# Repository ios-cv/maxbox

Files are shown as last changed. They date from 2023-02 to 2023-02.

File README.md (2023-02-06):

MaxBox open-source hardware
====================

This repository is for the 3D design files, KiCad PCB design/Gerber files, and ESP-IDF firmware files to produce a MaxBox control box. This takes the form of a 100mm diameter circular PCB with a Mifare antenna, buck converter capable of up to 36V DC input, RGB LEDs, high speed CAN bus transceiver, an ESP32-WROVER castellated module incorporating a Bluetooth and WiFi antenna, and GPIO to connect buttons and relays.

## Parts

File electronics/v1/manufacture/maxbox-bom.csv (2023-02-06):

Comment | Designator | Footprint | LCSC
10u 50V | C1 | Capacitor_SMD:C_0805_2012Metric | C440198
10u | C11,C25,C29 | Capacitor_SMD:C_0402_1005Metric | C15525
12p | C15,C16 | Capacitor_SMD:C_0805_2012Metric | C1792
122pF | C17,C18 | Capacitor_SMD:C_0603_1608Metric | C18438
41.8pF | C19,C22 | Capacitor_SMD:C_0805_2012Metric | C502147
4.7u 50V | C2 | Capacitor_SMD:C_1206_3216Metric | C29823
1n | C21 | Capacitor_SMD:C_0402_1005Metric | C1523
82.8pF | C23,C24 | Capacitor_SMD:C_0805_2012Metric | C105942
10p | C28 | Capacitor_SMD:C_0402_1005Metric | C32949
100n 50V | C3,C4 | Capacitor_SMD:C_0402_1005Metric | C307331
560p | C31,C32 | Capacitor_SMD:C_0402_1005Metric | C1537
1u | C5,C7 | Capacitor_SMD:C_0402_1005Metric | C52923
100n | C6,C10,C12,C13,C14,C20,C26,C27,C30,C35 | Capacitor_SMD:C_0402_1005Metric | C307331
22u | C8,C9,C33,C34 | Capacitor_SMD:C_0805_2012Metric | C45783
STATUS | D1 | LED_SMD:LED_0603_1608Metric | C72043
NUP2105L | D3 | Package_TO_SOT_SMD:SOT-23 | C284104
RGBLED | D4,D5,D6,D7,D8,D9,D10,D11 | maxlibrary:LED_FM-Z2727RGBA-SH | C727905
TC2030-IDC-NL_ESP | J1 | Connector:Tag-Connect_TC2030-IDC-NL_2x03_P1.27mm_Vertical
PICOBLADE | J2 | Connector_Molex:Molex_PicoBlade_53261-0671_1x06-1MP_P1.25mm_Horizontal | C99277
6.8uH | L1 | maxlibrary:L_Cenker_CKST0603 | C3002639
470nH | L2,L3 | Inductor_SMD:L_0805_2012Metric | C655211
AO3400A | Q1,Q2,Q3 | Package_TO_SOT_SMD:SOT-23 | C20917
100k 1% | R1 | Resistor_SMD:R_0402_1005Metric | C25741
470K | R11 | Resistor_SMD:R_0402_1005Metric | C25790
100K | R12 | Resistor_SMD:R_0402_1005Metric | C25741
470R | R13,R14 | Resistor_SMD:R_0402_1005Metric | C25117
100R | R15,R16 | Resistor_SMD:R_0402_1005Metric | C25076
43.2k 1% | R2 | Resistor_SMD:R_0603_1608Metric | C23172
75R | R21,R24,R27,R30,R33,R36,R39,R42 | Resistor_SMD:R_0402_1005Metric | C25133
33R | R22,R23,R25,R26,R28,R29,R31,R32,R34,R35,R37,R38,R40,R41,R43,R44 | Resistor_SMD:R_0402_1005Metric | C25105
1k | R3 | Resistor_SMD:R_0402_1005Metric | C11702
2.7k | R4,R17 | Resistor_SMD:R_0603_1608Metric | C13167
3.24R | R5,R6 | Resistor_SMD:R_0402_1005Metric | C270612
12K | R7,R9 | Resistor_SMD:R_0402_1005Metric | C25752
220R | R8,R10,R18,R19,R20 | Resistor_SMD:R_0402_1005Metric | C25091
RESET | SW1 | maxlibrary:XKB_TS-1187A-B-A-B | C318884
LMR33630ARNXT | U1 | maxlibrary:RNX0012B_VQFN-HR | C2861505
MFRC522 | U2 | Package_DFN_QFN:VQFN-32-1EP_5x5mm_P0.5mm_EP3.5x3.5mm_ThermalVias | C11322
ESP32-WROOM-32E-N4 | U3 | RF_Module:ESP32-WROOM-32 | C701341
SN65HVD230 | U4 | Package_SO:SOIC-8_3.9x4.9mm_P1.27mm | C12084
27.12MHz | Y1 | Crystal:Crystal_SMD_3225-4Pin_3.2x2.5mm | C113669

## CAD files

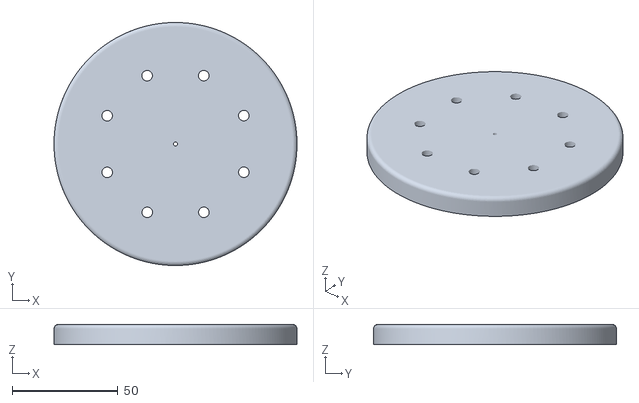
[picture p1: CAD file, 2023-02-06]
case/case-top.stl
115.0 x 115.0 x 9.50

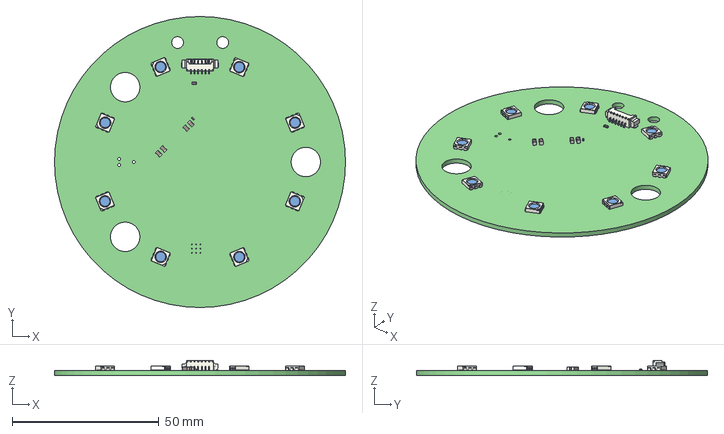
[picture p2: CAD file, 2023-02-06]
case/pcb-v1.step
99.0 x 99.0 x 5.05 mm
CanHireEV PCB

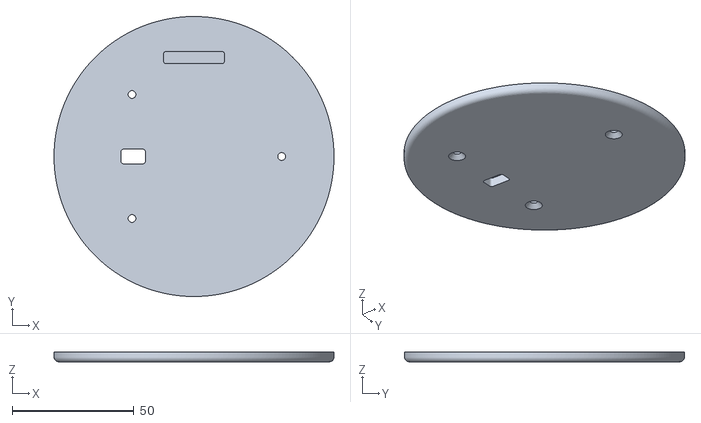
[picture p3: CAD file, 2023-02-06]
case/case-bottom.stl
115.0 x 115.0 x 4.00

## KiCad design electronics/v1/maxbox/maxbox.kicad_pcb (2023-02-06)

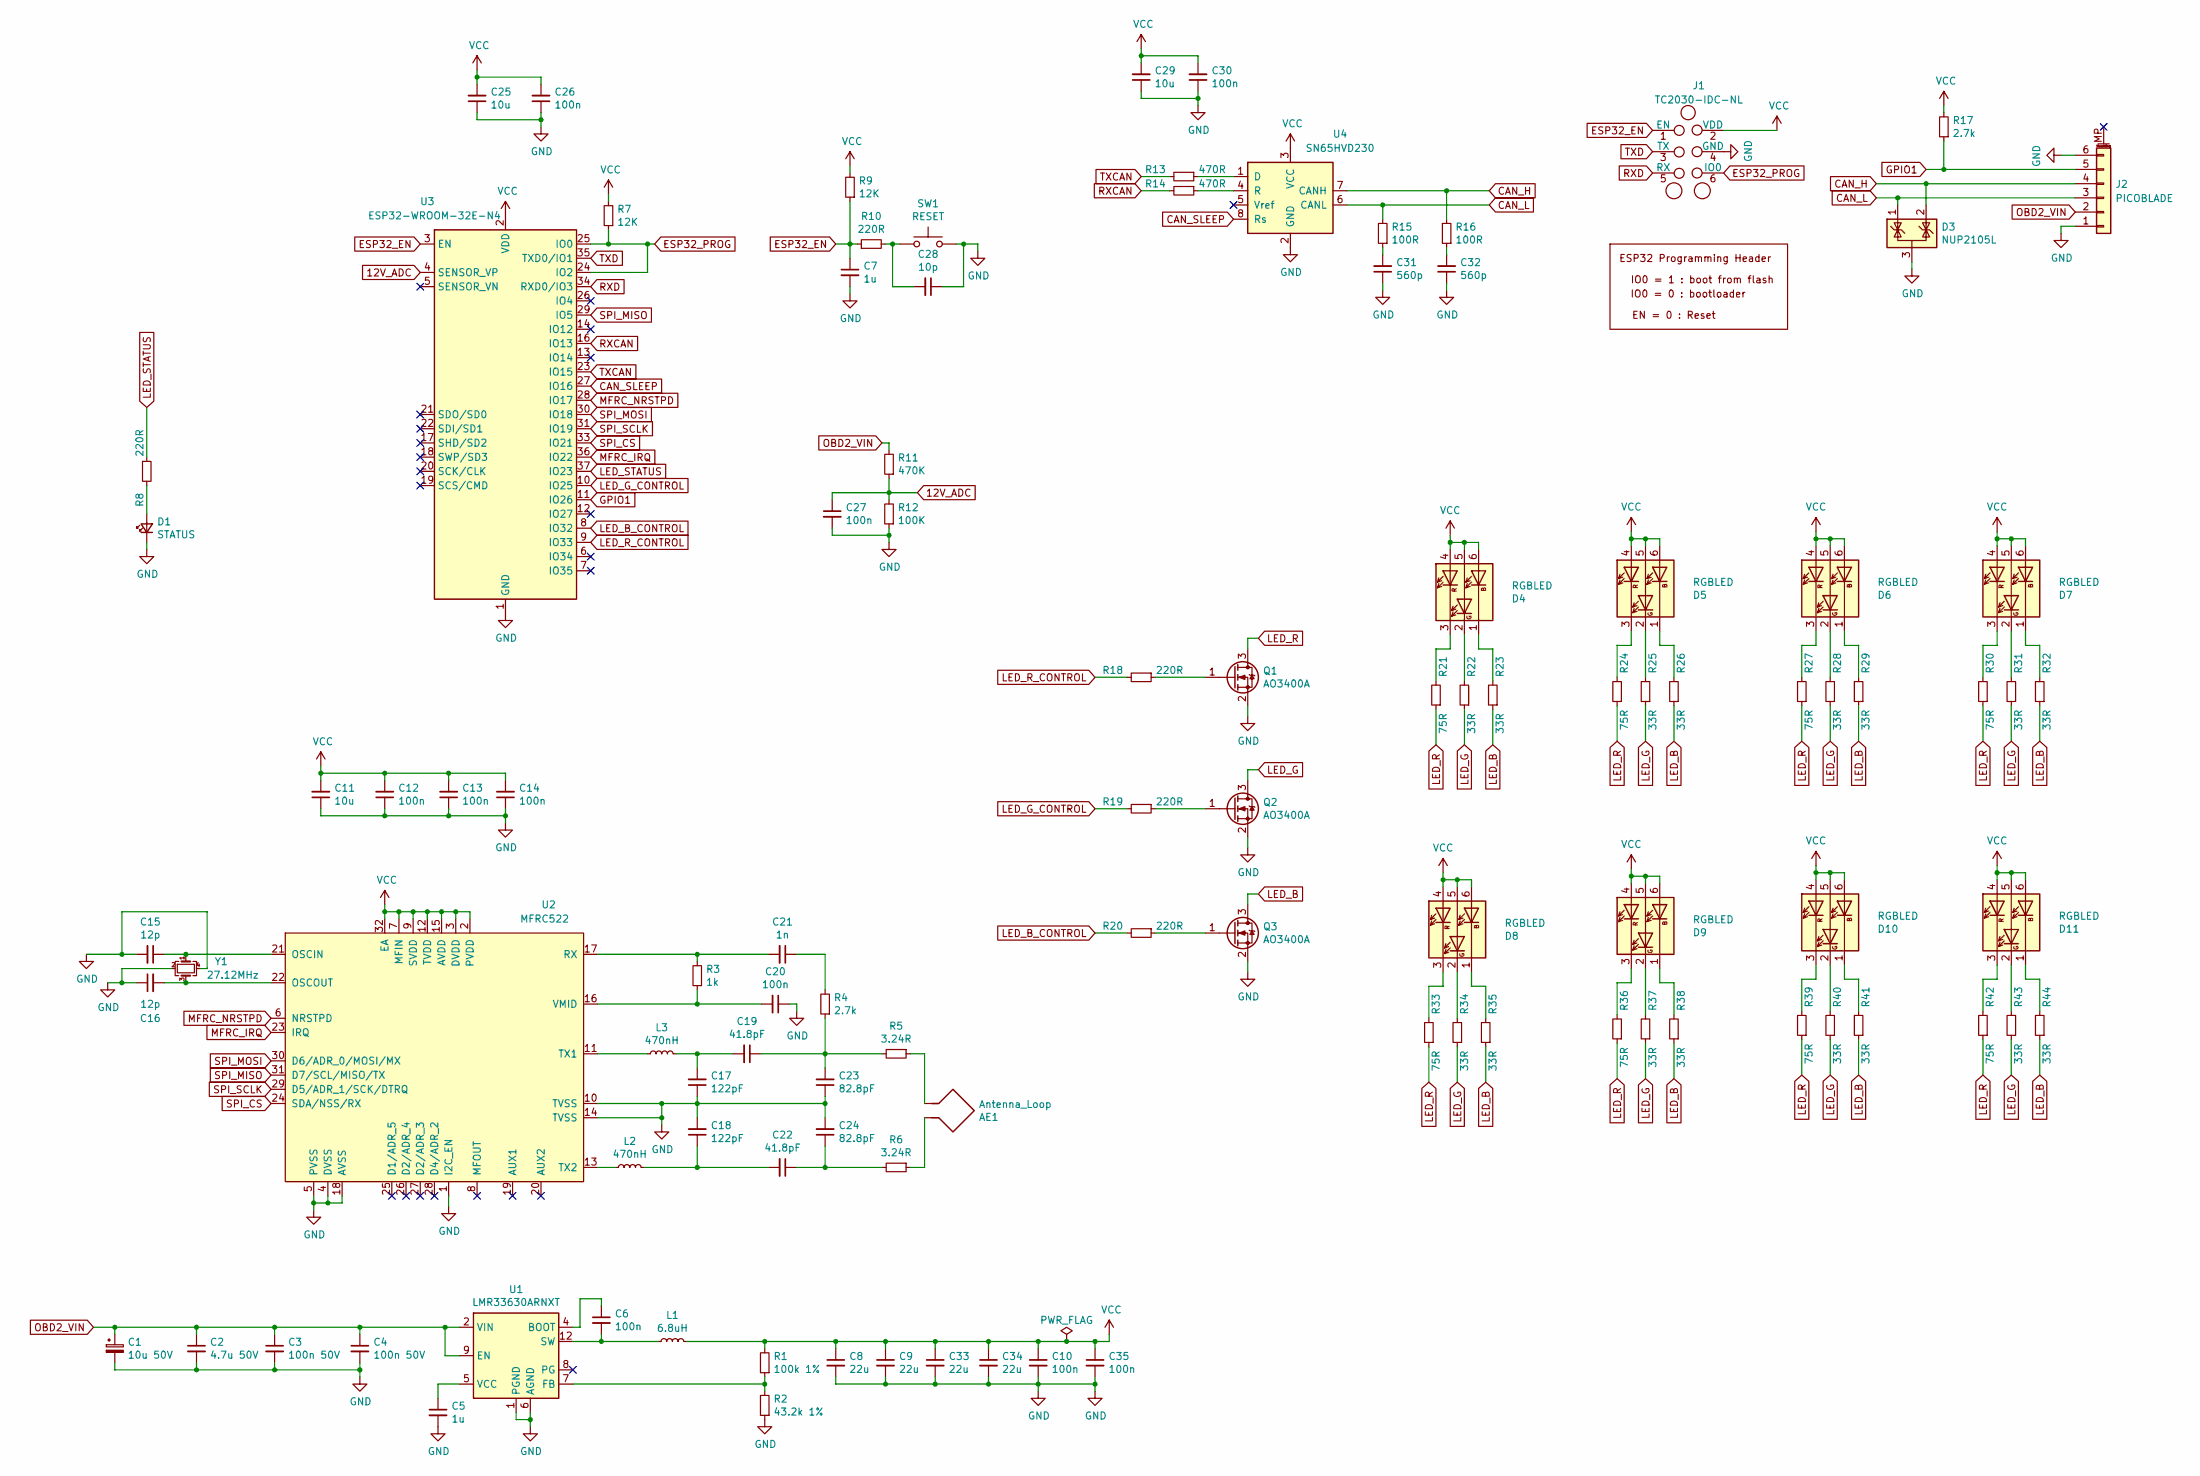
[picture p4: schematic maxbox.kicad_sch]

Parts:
AE1: Antenna_Loop; 95mm-3turn-antenna
C1: 10u 50V; C_0805_2012Metric; LCSC C440198
C2: 4.7u 50V; C_1206_3216Metric; LCSC C29823
C3, C4: 100n 50V; C_0402_1005Metric; LCSC C307331
C5, C7: 1u; C_0402_1005Metric; LCSC C52923
C6, C10, C12, C13, C14, C20, C26, C27, C30, C35: 100n; C_0402_1005Metric; LCSC C307331
C8, C9, C33, C34: 22u; C_0805_2012Metric; LCSC C45783
C11, C25, C29: 10u; C_0402_1005Metric; LCSC C15525
C15, C16: 12p; C_0805_2012Metric; LCSC C1792
C17, C18: 122pF; C_0603_1608Metric; LCSC C18438
C19, C22: 41.8pF; C_0805_2012Metric; LCSC C502147
C21: 1n; C_0402_1005Metric; LCSC C1523
C23, C24: 82.8pF; C_0805_2012Metric; LCSC C105942
C28: 10p; C_0402_1005Metric; LCSC C32949
C31, C32: 560p; C_0402_1005Metric; LCSC C1537
D1: STATUS; LED_0603_1608Metric; LCSC C72043
D3: NUP2105L; SOT-23; LCSC C284104
D4, D5, D6, D7, D8, D9, D10, D11: RGBLED; LED_FM-Z2727RGBA-SH; LCSC C727905
J1: TC2030-IDC-NL_ESP; Tag-Connect_TC2030-IDC-NL_2x03_P1.27mm_Vertical
J2: PICOBLADE; Molex_PicoBlade_53261-0671_1x06-1MP_P1.25mm_Horizontal; LCSC C99277
L1: 6.8uH; L_Cenker_CKST0603; LCSC C3002639
L2, L3: 470nH; L_0805_2012Metric; LCSC C655211
Q1, Q2, Q3: AO3400A; SOT-23; LCSC C20917
R1: 100k 1%; R_0402_1005Metric; LCSC C25741
R2: 43.2k 1%; R_0603_1608Metric; LCSC C23172
R3: 1k; R_0402_1005Metric; LCSC C11702
R4, R17: 2.7k; R_0603_1608Metric; LCSC C13167
R5, R6: 3.24R; R_0402_1005Metric; LCSC C270612
R7, R9: 12K; R_0402_1005Metric; LCSC C25752
R8, R10, R18, R19, R20: 220R; R_0402_1005Metric; LCSC C25091
R11: 470K; R_0402_1005Metric; LCSC C25790
R12: 100K; R_0402_1005Metric; LCSC C25741
R13, R14: 470R; R_0402_1005Metric; LCSC C25117
R15, R16: 100R; R_0402_1005Metric; LCSC C25076
R21, R24, R27, R30, R33, R36, R39, R42: 75R; R_0402_1005Metric; LCSC C25133
R22, R23, R25, R26, R28, R29, R31, R32, R34, R35, R37, R38, R40, R41, R43, R44: 33R; R_0402_1005Metric; LCSC C25105
SW1: RESET; XKB_TS-1187A-B-A-B; LCSC C318884
U1: LMR33630ARNXT; RNX0012B_VQFN-HR; LCSC C2861505
U2: MFRC522; VQFN-32-1EP_5x5mm_P0.5mm_EP3.5x3.5mm_ThermalVias; LCSC C11322
U3: ESP32-WROOM-32E-N4; ESP32-WROOM-32; LCSC C701341
U4: SN65HVD230; SOIC-8_3.9x4.9mm_P1.27mm; LCSC C12084
Y1: 27.12MHz; Crystal_SMD_3225-4Pin_3.2x2.5mm; LCSC C113669

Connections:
12V_ADC: C27.1, R11.1, R12.2, U3.4 (SENSOR_VP)
CAN_H: D3.2 (K), J2.4, R16.2, U4.7 (CANH)
CAN_L: D3.1 (K), J2.3, R15.2, U4.6 (CANL)
CAN_SLEEP: U3.27 (IO16), U4.8 (Rs)
ESP32_EN: C7.1, J1.1 (EN), R9.1, R10.1, U3.3 (EN)
ESP32_PROG: J1.6 (IO0), R7.1, U3.24 (IO2), U3.25 (IO0)
GND: C1.2, C2.2, C3.2, C4.2, C5.2, C7.2, C8.2, C9.2, C10.2, C11.1, C12.1, C13.1, C14.1, C15.2, C16.1, C17.1, C18.2, C20.1, C23.1, C24.2, C25.1, C26.1, C27.2, C28.1, C29.1, C30.1, C31.1, C32.1, C33.2, C34.2, C35.2, D1.1 (K), D3.3 (A), J1.4 (GND), J2.1, J2.6, Q1.2 (S), Q2.2 (S), Q3.2 (S), R2.1, R12.1, SW1.2, U1.1 (PGND), U1.6 (AGND), U1.11 (PGND), U2.1 (I2C_EN), U2.4 (DVSS), U2.5 (PVSS), U2.10 (TVSS), U2.14 (TVSS), U2.18 (AVSS), U3.1 (GND), U3.15 (GND), U3.38 (GND), U3.39 (GND), U4.2 (GND), Y1.2, Y1.4
GPIO1: J2.5, R17.1, U3.11 (IO26)
LED_B: Q3.3 (D), R23.1, R26.1, R29.1, R32.1, R35.1, R38.1, R41.1, R44.1
LED_B_CONTROL: R20.2, U3.8 (IO32)
LED_G: Q2.3 (D), R22.1, R25.1, R28.1, R31.1, R34.1, R37.1, R40.1, R43.1
LED_G_CONTROL: R19.2, U3.10 (IO25)
LED_R: Q1.3 (D), R21.1, R24.1, R27.1, R30.1, R33.1, R36.1, R39.1, R42.1
LED_R_CONTROL: R18.2, U3.9 (IO33)
LED_STATUS: R8.1, U3.37 (IO23)
MFRC_IRQ: U2.23 (IRQ), U3.36 (IO22)
MFRC_NRSTPD: U2.6 (NRSTPD), U3.28 (IO17)
unnamed: AE1.1, R6.1
unnamed: AE1.2, R5.1
unnamed: C5.1, U1.5 (VCC)
unnamed: C6.1, U1.4 (BOOT)
unnamed: C6.2, L1.1, U1.3 (NC), U1.12 (SW)
unnamed: C15.1, U2.21 (OSCIN), Y1.1
unnamed: C16.2, U2.22 (OSCOUT), Y1.3
unnamed: C17.2, C19.2, L3.2
unnamed: C18.1, C22.2, L2.2
unnamed: C19.1, C23.2, R4.1, R5.2
unnamed: C20.2, R3.1, U2.16 (VMID)
unnamed: C21.1, R4.2
unnamed: C21.2, R3.2, U2.17 (RX)
unnamed: C22.1, C24.1, R6.2
unnamed: C28.2, R10.2, SW1.1
unnamed: C31.2, R15.1
unnamed: C32.2, R16.1
unnamed: D1.2 (A), R8.2
unnamed: D4.1 (KB), R23.2
unnamed: D4.2 (KG), R22.2
unnamed: D4.3 (KR), R21.2
unnamed: D5.1 (KB), R26.2
unnamed: D5.2 (KG), R25.2
unnamed: D5.3 (KR), R24.2
unnamed: D6.1 (KB), R29.2
unnamed: D6.2 (KG), R28.2
unnamed: D6.3 (KR), R27.2
unnamed: D7.1 (KB), R32.2
unnamed: D7.2 (KG), R31.2
unnamed: D7.3 (KR), R30.2
unnamed: D8.1 (KB), R35.2
unnamed: D8.2 (KG), R34.2
unnamed: D8.3 (KR), R33.2
unnamed: D9.1 (KB), R38.2
unnamed: D9.2 (KG), R37.2
unnamed: D9.3 (KR), R36.2
unnamed: D10.1 (KB), R41.2
unnamed: D10.2 (KG), R40.2
unnamed: D10.3 (KR), R39.2
unnamed: D11.1 (KB), R44.2
unnamed: D11.2 (KG), R43.2
unnamed: D11.3 (KR), R42.2
unnamed: L2.1, U2.13 (TX2)
unnamed: L3.1, U2.11 (TX1)
unnamed: Q1.1 (G), R18.1
unnamed: Q2.1 (G), R19.1
unnamed: Q3.1 (G), R20.1
unnamed: R1.1, R2.2, U1.7 (FB)
unnamed: R13.1, U4.1 (D)
unnamed: R14.1, U4.4 (R)
OBD2_VIN: C1.1, C2.1, C3.1, C4.1, J2.2, R11.2, U1.2 (VIN), U1.9 (EN), U1.10 (VIN)
RXCAN: R14.2, U3.16 (IO13)
RXD: J1.5 (RX), U3.34 (RXD0/IO3)
SPI_CS: U2.24 (SDA/NSS/RX), U3.33 (IO21)
SPI_MISO: U2.31 (D7/SCL/MISO/TX), U3.29 (IO5)
SPI_MOSI: U2.30 (D6/ADR_0/MOSI/MX), U3.30 (IO18)
SPI_SCLK: U2.29 (D5/ADR_1/SCK/DTRQ), U3.31 (IO19)
TXCAN: R13.2, U3.23 (IO15)
TXD: J1.3 (TX), U3.35 (TXD0/IO1)
VCC: C8.1, C9.1, C10.1, C11.2, C12.2, C13.2, C14.2, C25.2, C26.2, C29.2, C30.2, C33.1, C34.1, C35.1, D4.4 (AR), D4.5 (AG), D4.6 (AB), D5.4 (AR), D5.5 (AG), D5.6 (AB), D6.4 (AR), D6.5 (AG), D6.6 (AB), D7.4 (AR), D7.5 (AG), D7.6 (AB), D8.4 (AR), D8.5 (AG), D8.6 (AB), D9.4 (AR), D9.5 (AG), D9.6 (AB), D10.4 (AR), D10.5 (AG), D10.6 (AB), D11.4 (AR), D11.5 (AG), D11.6 (AB), J1.2 (VDD), L1.2, R1.2, R7.2, R9.2, R17.2, U2.2 (PVDD), U2.3 (DVDD), U2.7 (MFIN), U2.9 (SVDD), U2.12 (TVDD), U2.15 (AVDD), U2.32 (EA), U3.2 (VDD), U4.3 (VCC)

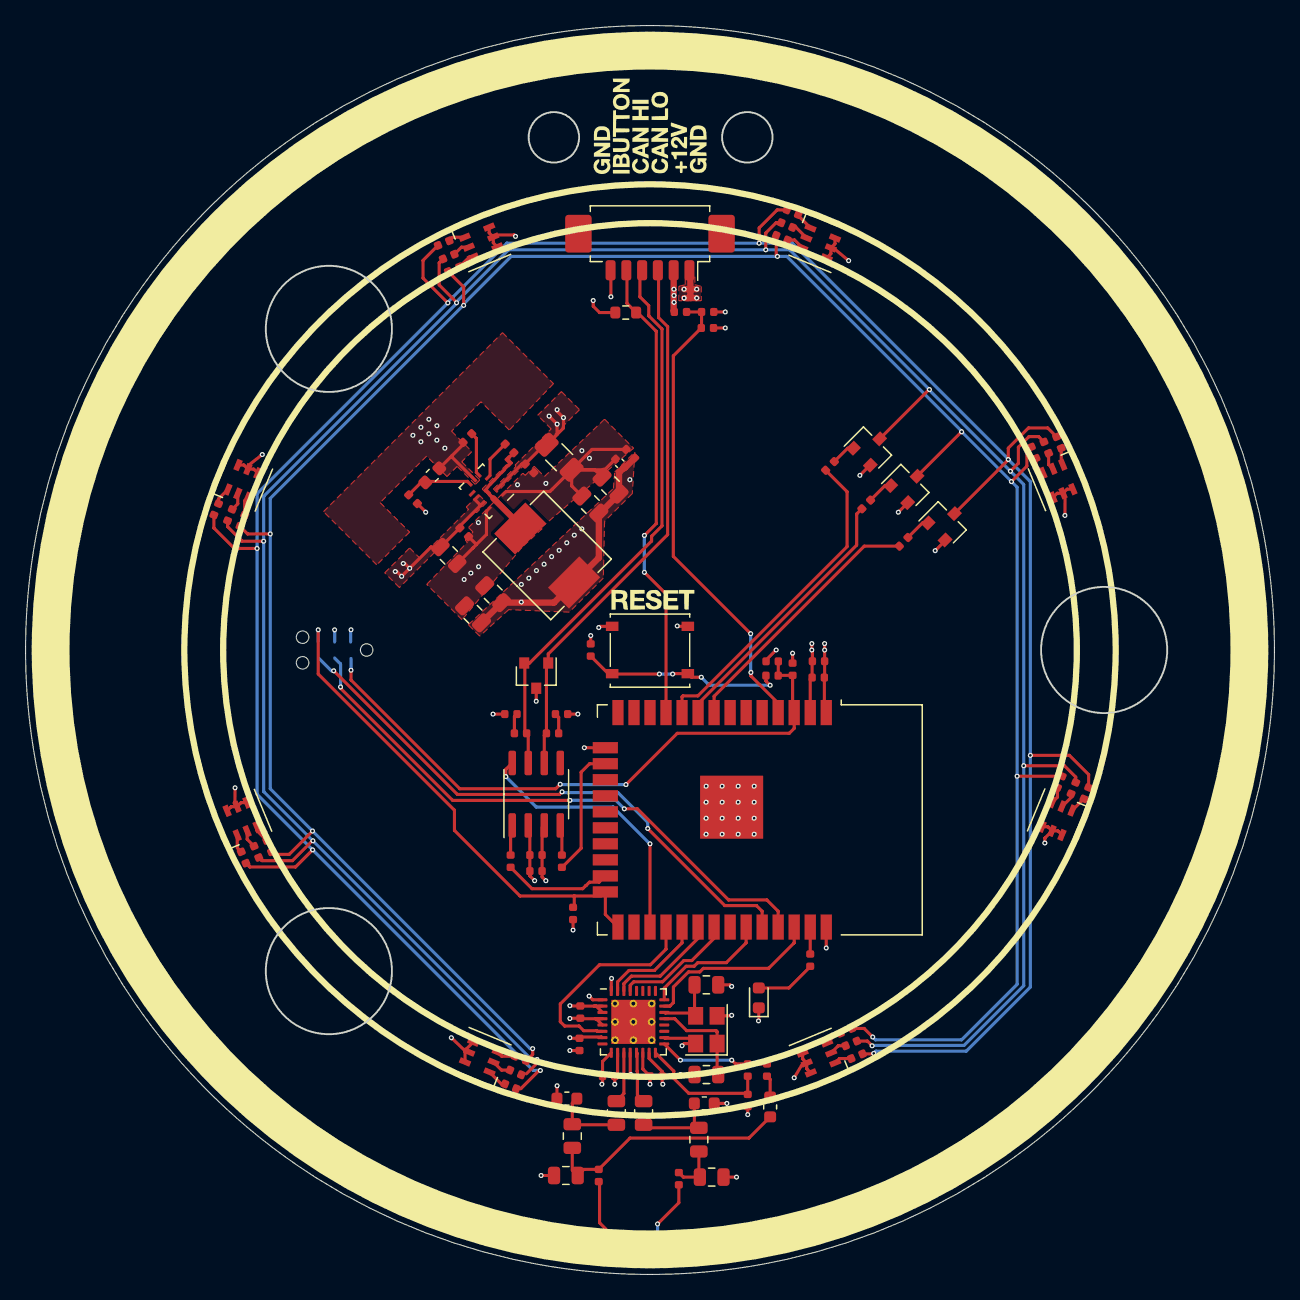
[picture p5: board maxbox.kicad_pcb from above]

Board: 4 copper layers, 99.0 x 99.0 mm, 104 parts (1 on the bottom side), 77 nets.

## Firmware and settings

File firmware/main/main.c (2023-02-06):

#include "stdio.h"
#include "string.h"
#include "driver/gpio.h"
#include "inttypes.h"

#include "freertos/FreeRTOS.h"
#include "freertos/event_groups.h"
#include "freertos/task.h"
#include "pthread.h"

#include "esp_log.h"
#include "driver/adc.h"
#include "esp_adc_cal.h"

#include "nvs_flash.h"
#include "cJSON.h"

#include "rc522.h"
#include "network.h"
#include "vehicle.h"
#include "led.h"
#include "owb.h"

#include <time.h>
#include <sys/time.h>
#include "freertos/task.h"
#include "driver/uart.h"
#include "esp_sleep.h"
#include "esp_log.h"
#include "esp_timer.h"
#include "esp_check.h"

// GPIO

#define RFID_MISO_PIN   5
#define RFID_MOSI_PIN   18
#define RFID_SCK_PIN    19
#define RFID_SDA_PIN    21
#define RFID_NRSTPD_PIN 17
#define RFID_IRQ_PIN    22

#define CAN_TX_PIN      15
#define CAN_RX_PIN      13
#define CAN_SLEEP_PIN   16

#define ONEWIRE_PIN     26

#define API_ENDPOINT_TOUCH          CONFIG_API_ROOT "touch"
#define API_ENDPOINT_TELEMETRY      CONFIG_API_ROOT "telemetry"

#define MAX_OPERATOR_CARDS          32

#define TAG_CHECK_INTERVAL_MS       500
#define TELEMETRY_SEND_INTERVAL_MS  120000

#define TELEMETRY_TIMEOUT_MS        8000
#define TOUCH_TIMEOUT_MS            20000

/* FreeRTOS event group to signal when it's safe to power off*/
EventGroupHandle_t s_status_group;

#define TELEMETRY_SENDING_BIT   BIT0 // currently sending telemetry
#define TELEMETRY_DONE_BIT      BIT1 // telemetry is sent
#define TAG_PROCESSING_BIT      BIT2 // currently processing a tag
#define TAG_DONE_BIT            BIT3 // tag processing is finished
#define FIRMWARE_UPDATING_BIT   BIT4 // firmware update in progress

static const char* TAG = "MaxBox";
static esp_adc_cal_characteristics_t adc1_chars;
rest_request_t touch_req;
rest_request_t telemetry_req;

char firmware_update_url[255] = {0};

struct maxbox {
    vehicle_t vehicle;
    int operator_car_lock;
    char operator_card_list[MAX_OPERATOR_CARDS][9];
};

int etag = -1;

OneWireBus * owb;
owb_rmt_driver_info rmt_driver_info;

typedef struct maxbox* maxbox_handle_t;

static maxbox_handle_t hndl = NULL;

static void io_init(void)
{
    // Power up the MFRC522
    gpio_set_direction(RFID_NRSTPD_PIN, GPIO_MODE_OUTPUT);
    gpio_set_level(RFID_NRSTPD_PIN, 1);

    // TODO: Sleep CAN transmitter until required (to save power) 
    // For the moment we just leave it awake all the time
    gpio_set_direction(CAN_SLEEP_PIN, GPIO_MODE_OUTPUT);
    gpio_set_level(CAN_SLEEP_PIN, 0);

    adc1_config_width(ADC_WIDTH_BIT_12);
    adc1_config_channel_atten(ADC1_CHANNEL_0,ADC_ATTEN_DB_11);
}

static void flash_init(void)
{
    //Initialize NVS
    esp_err_t ret = nvs_flash_init();
    if (ret == ESP_ERR_NVS_NO_FREE_PAGES || ret == ESP_ERR_NVS_NEW_VERSION_FOUND) {
      ESP_ERROR_CHECK(nvs_flash_erase());
      ret = nvs_flash_init();
    }
    ESP_ERROR_CHECK(ret);

    uint8_t base_mac[6] = {0};
    ESP_ERROR_CHECK(esp_read_mac(base_mac, ESP_MAC_WIFI_STA));

    ESP_LOGI(TAG, "Loaded NVS. Base MAC address %02x%02x%02x%02x%02x%02x", base_mac[0], base_mac[1], base_mac[2], base_mac[3], base_mac[4], base_mac[5]);

    nvs_handle_t my_handle;
    esp_err_t err = nvs_open("storage", NVS_READWRITE, &my_handle);
    if (err != ESP_OK) {
        ESP_LOGE(TAG, "Error (%s) opening NVS handle!", esp_err_to_name(err));
    } else {
        ESP_LOGI(TAG, "Reading operator card list from NVS ...");
        nvs_get_i32(my_handle, "etag", &etag);

        size_t required_size = sizeof(hndl->operator_card_list);
        nvs_get_blob(my_handle, "op_card_list", hndl->operator_card_list, &required_size);
        if (err == ESP_OK)
        {
            ESP_LOGI(TAG, "Loaded etag: %i", etag);
            int i;
            for (i=0; i<MAX_OPERATOR_CARDS; i++)
            {
                if (strcmp(hndl->operator_card_list[i], "voidvoid") != 0)
                {
                    ESP_LOGI(TAG, "Operator card %i: %s", i+1, hndl->operator_card_list[i]);
                }
            }
        }
        else if (err == ESP_ERR_NVS_NOT_FOUND)
        {
            ESP_LOGI(TAG, "No etag value written in flash");
        }
        else
        {
            ESP_LOGE(TAG, "Error (%s) reading flash", esp_err_to_name(err));
        }
    }
}

void json_touch_handler(char* result)
{
    cJSON *result_json = cJSON_Parse(result);
    
    if(cJSON_GetObjectItem(result_json, "action"))
    {
        char *action = cJSON_GetObjectItem(result_json, "action")->valuestring;
        
        if (strcmp(action, "lock") == 0)
        {
            vehicle_lock_doors();
        } 
        else if (strcmp(action, "unlock") == 0)
        {
            vehicle_unlock_doors();
        } 
        else if (strcmp(action, "reject") == 0)
        {
            ESP_LOGI(TAG, "Request rejected");

            led_update(DENY); 
            vTaskDelay(1000 / portTICK_PERIOD_MS);
            led_update(IDLE);

            xEventGroupSetBits(s_status_group, TAG_DONE_BIT);
        } 
    }
    else
    {
        ESP_LOGE(TAG, "Card unlock error");

        led_update(ERROR);
        vTaskDelay(2000 / portTICK_PERIOD_MS);
        led_update(IDLE);

        xEventGroupSetBits(s_status_group, TAG_DONE_BIT);
    }

    cJSON_Delete(result_json);

}

void json_telemetry_handler(char* result)
{
    cJSON *result_json = cJSON_Parse(result);

    if(cJSON_GetObjectItem(result_json, "operator_card_list"))
    {
        cJSON *card_list = cJSON_GetObjectItem(result_json, "operator_card_list");
        cJSON *recv_etag = cJSON_GetObjectItem(card_list, "etag");

        if (cJSON_IsNumber(recv_etag))
        {
            if (recv_etag->valuedouble != etag)
            {
                ESP_LOGI(TAG, "New etag is %d", recv_etag->valueint);

                cJSON *card;
                cJSON *op_cards = cJSON_GetObjectItem(card_list, "cards");
                int i = 0;
                cJSON_ArrayForEach(card, op_cards)
                {
                    char *cardid = card->valuestring;
                    ESP_LOGI(TAG, "Added card to operator list with id: %s", cardid);
                    strncpy(hndl->operator_card_list[i], cardid, 9);
                    i++;
                }

                for (; i<MAX_OPERATOR_CARDS; i++)
                {
                    strcpy(hndl->operator_card_list[i], "voidvoid");
                }

                etag = recv_etag->valuedouble;
                
                nvs_handle_t my_handle;

                esp_err_t err = nvs_open("storage", NVS_READWRITE, &my_handle);
                if (err != ESP_OK) {
                    ESP_LOGE(TAG, "Error (%s) opening NVS handle!", esp_err_to_name(err));
                } else {

                ESP_LOGI(TAG, "Writing operator card to NVS...");

                nvs_set_i32(my_handle, "etag", etag);

                size_t required_size = sizeof(hndl->operator_card_list);
                nvs_set_blob(my_handle, "op_card_list", hndl->operator_card_list, required_size);
            }
            }
        }
    }

    // Optionally, there may be an action to manually lock or unlock the car remotely
    if(cJSON_GetObjectItem(result_json, "action"))
    {
        char *action = cJSON_GetObjectItem(result_json, "action")->valuestring;
        if (strcmp(action, "lock") == 0)
        {
            vehicle_lock_doors();
        } 
        else if (strcmp(action, "unlock") == 0)
        {
            vehicle_unlock_doors();
        }
    }

    if(cJSON_GetObjectItem(result_json, "firmware_update_url"))
    {
        char *fw_url = cJSON_GetObjectItem(result_json, "firmware_update_url")->valuestring;
        strcpy(firmware_update_url, fw_url);
        ESP_LOGI(TAG, "Firmware update detected, updating from URL %s", firmware_update_url);
        xEventGroupSetBits(s_status_group, FIRMWARE_UPDATING_BIT);      
        xTaskCreate(firmware_update, "firmware_update", 8192, NULL, 5, NULL);
    } 

    cJSON_Delete(result_json);

    if(pthread_mutex_lock(&hndl->vehicle->telemetrymux) == 0) // make sure telemetry isn't being updated as we reset it
    {
        hndl->vehicle->soc_percent = -1;
        hndl->vehicle->odometer_miles = -1;
        hndl->vehicle->doors_locked = -1;
        pthread_mutex_unlock(&hndl->vehicle->telemetrymux);
    }
    
    ESP_LOGI(TAG, "Finished sending telemetry");
    xEventGroupClearBits(s_status_group, TELEMETRY_SENDING_BIT);        
    xEventGroupSetBits(s_status_group, TELEMETRY_DONE_BIT);
}

static void update_ibutton_id(void)
{
    OneWireBus_SearchState search_state = {0};
    bool found = false;
    ESP_LOGI(TAG, "Searching for iButton...");
    owb_search_first(owb, &search_state, &found);
    OneWireBus_ROMCode device_rom_code;

    if(pthread_mutex_lock(&hndl->vehicle->telemetrymux) == 0) // make sure telemetry isn't being updated as we set it
    {
        hndl->vehicle->ibutton_id[0] = '\0';
        esp_err_t err = owb_read_rom(owb, &device_rom_code);

        if (err == ESP_OK) {
            owb_string_from_rom_code(device_rom_code, hndl->vehicle->ibutton_id, sizeof(hndl->vehicle->ibutton_id));
        }

        pthread_mutex_unlock(&hndl->vehicle->telemetrymux);
    }
}

static void tag_handler(uint8_t* sn) // serial number is always 4 bytes long
{
    xEventGroupSetBits(s_status_group, TAG_PROCESSING_BIT);
    led_update(PROCESSING);

    char card_id[9];
    sprintf(card_id, "%02x%02x%02x%02x", sn[0], sn[1], sn[2], sn[3]);

    ESP_LOGI(TAG, "Detected card %s", card_id);

    // // wait for telemetry to return if we're already in the middle of an HTTP request.
    // // for some reason, sending an HTTP request if we're already waiting for a response
    // // can cause confusing behaviour (the JSON response sometimes gets sent to the wrong
    // // callback function) so easier just to wait.

    // if(xEventGroupGetBits(s_status_group) & TELEMETRY_SENDING_BIT)
    // {
    //     ESP_LOGI(TAG, "Waiting for telemetry operation to finish before processing card");
    //     xEventGroupWaitBits(s_status_group,
    //     TELEMETRY_DONE_BIT,
    //     pdFALSE,
    //     pdFALSE,
    //     TELEMETRY_TIMEOUT_MS/portTICK_PERIOD_MS);
    // }

    // first let's check if this is a tag in our operator card list
    int i;
    for (i=0; i<MAX_OPERATOR_CARDS; i++)
    {
        if (strcmp(hndl->operator_card_list[i], card_id) == 0)
        {
            if (hndl->operator_car_lock == 0)
            {
                ESP_LOGI(TAG, "Operator card detected, locking");
                vehicle_lock_doors();
                hndl->operator_car_lock = 1;
            }
            else
            {
                ESP_LOGI(TAG, "Operator card detected, unlocking");
                vehicle_unlock_doors();
                hndl->operator_car_lock = 0;
            }
            return;
        }
    }

    wifi_reconnect();

    ESP_LOGI(TAG, "Not an operator tag, reconnecting to wifi");

    cJSON *root;
    root=cJSON_CreateObject();
    cJSON_AddItemToObject(root, "card_id", cJSON_CreateString(card_id));

    update_ibutton_id();

    cJSON_AddStringToObject(root, "ibutton_id",  hndl->vehicle->ibutton_id);

    char *rendered=cJSON_Print(root);
    strcpy(touch_req.data, rendered);

    cJSON_Delete(root);
    free(rendered);

    touch_req.callback = json_touch_handler;
    touch_req.url = API_ENDPOINT_TOUCH;
    touch_req.alert_on_error = pdTRUE;

    xTaskCreate(&http_auth_rfid, "http_auth_rfid", 8192, &touch_req, 2, NULL);
}

static void update_battery_voltage(void)
{
    uint32_t voltage_raw = adc1_get_raw(ADC1_CHANNEL_0);
    uint32_t voltage_mv = esp_adc_cal_raw_to_voltage(voltage_raw, &adc1_chars);
    float voltage = (float)voltage_mv / 179;

    if(pthread_mutex_lock(&hndl->vehicle->telemetrymux) == 0) // make sure telemetry isn't being updated as we set it
    {
        hndl->vehicle->aux_battery_voltage = voltage;
        pthread_mutex_unlock(&hndl->vehicle->telemetrymux);
    }
}

static bool adc_calibration_init(void)
{
    esp_err_t ret;
    bool cali_enable = false;

    ret = esp_adc_cal_check_efuse(ESP_ADC_CAL_VAL_EFUSE_VREF);
    if (ret == ESP_ERR_NOT_SUPPORTED) {
        ESP_LOGW(TAG, "Calibration scheme not supported, skip software calibration");
    } else if (ret == ESP_ERR_INVALID_VERSION) {
        ESP_LOGW(TAG, "eFuse not burnt, skip software calibration");
    } else if (ret == ESP_OK) {
        cali_enable = true;
        esp_adc_cal_characterize(ADC_UNIT_1, ADC_ATTEN_DB_11, ADC_WIDTH_BIT_12, 0, &adc1_chars);
        ESP_LOGI(TAG, "ADC calibrated");
    } else {
        ESP_LOGE(TAG, "ADC calibration failed");
    }

    return cali_enable;
}

static void init_rfid(void)
{
    const rc522_start_args_t start_args = {
        .miso_io  = 5,
        .mosi_io  = 18,
        .sck_io   = 19,
        .sda_io   = 21,
        .callback = &tag_handler,
        .spi_host_id = VSPI_HOST
    };

    rc522_init(&start_args);
}

static void telemetry_loop(void *args)
{
    while (true) {
        if (xEventGroupGetBits(s_status_group) & TAG_PROCESSING_BIT)
        {
            ESP_LOGI(TAG, "Tag operation in progress, waiting to send telemetry");
            // don't send telemetry if we're already processing a tag
            xEventGroupWaitBits(s_status_group,
            TAG_DONE_BIT,
            pdTRUE,
            pdFALSE,
            TOUCH_TIMEOUT_MS/portTICK_PERIOD_MS);
            continue;
        }

        if (xEventGroupGetBits(s_status_group) & FIRMWARE_UPDATING_BIT)
        {
            ESP_LOGI(TAG, "Firmware update in progress, not sending telemetry");
            vTaskDelay(60000 / portTICK_PERIOD_MS);
            continue;
        }

        uint32_t free_heap_size = esp_get_free_heap_size();
        ESP_LOGI(TAG, "Free heap is %zu", free_heap_size);

        xEventGroupSetBits(s_status_group, TELEMETRY_SENDING_BIT);
        xEventGroupClearBits(s_status_group, TELEMETRY_DONE_BIT);

        led_update(HEARTBEAT);
        ESP_LOGI(TAG, "Reconnecting wifi to send telemetry");
        wifi_reconnect();

        cJSON *root, *tel;
        root=cJSON_CreateObject();
        cJSON_AddItemToObject(root, "telemetry", tel=cJSON_CreateObject());

        if (hndl->vehicle->soc_percent != -1)
        {
            cJSON_AddNumberToObject(tel, "soc_percent", hndl->vehicle->soc_percent);
        }
        if (hndl->vehicle->odometer_miles != -1)
        {
            cJSON_AddNumberToObject(tel, "odometer_miles", hndl->vehicle->odometer_miles);
        }
        if (hndl->vehicle->doors_locked != -1)
        {
            cJSON_AddNumberToObject(tel, "doors_locked", hndl->vehicle->doors_locked);
        }

        update_battery_voltage();
        cJSON_AddNumberToObject(tel, "aux_battery_voltage",  hndl->vehicle->aux_battery_voltage);

        update_ibutton_id();

        cJSON_AddStringToObject(tel, "ibutton_id",  hndl->vehicle->ibutton_id);

        cJSON_AddNumberToObject(tel, "box_uptime_s", esp_timer_get_time()/1000000);

        cJSON_AddNumberToObject(tel, "box_free_heap_bytes", esp_get_free_heap_size());

        char *rendered=cJSON_Print(root);

        strcpy(telemetry_req.data, rendered);

        cJSON_Delete(root);
        free(rendered);

        telemetry_req.callback = json_telemetry_handler;
        telemetry_req.url = API_ENDPOINT_TELEMETRY;
        telemetry_req.alert_on_error = pdFALSE;

        xTaskCreate(http_auth_rfid, "http_auth_rfid", 8192, &telemetry_req, 2, NULL);

        xEventGroupWaitBits(s_status_group,
        TELEMETRY_DONE_BIT,
        pdTRUE,
        pdFALSE,
        TELEMETRY_TIMEOUT_MS/portTICK_PERIOD_MS);

        xEventGroupClearBits(s_status_group, TELEMETRY_SENDING_BIT);

        if(xEventGroupGetBits(s_status_group) & TAG_PROCESSING_BIT)
        {
            ESP_LOGI(TAG,"Not disconnecting wifi - tag handling operation in progress");
        }
        else if(xEventGroupGetBits(s_status_group) & FIRMWARE_UPDATING_BIT)
        {
            ESP_LOGI(TAG,"Not disconnecting wifi - firmware update in progress");
        }
        else
        {
            ESP_LOGI(TAG, "Telemetry sent, disconnecting wifi");
            wifi_disconnect();

        }

        vTaskDelay(TELEMETRY_SEND_INTERVAL_MS / portTICK_PERIOD_MS);

    }
    vTaskDelete(NULL);
}

static void tag_loop(void *args)
{
    while (true) {
        // is there a tag?
        uint8_t* serial_no = rc522_get_tag();

        if(serial_no)
        {
            ESP_LOGI(TAG, "Processing tag");
            xEventGroupClearBits(s_status_group, TAG_DONE_BIT);
            xEventGroupSetBits(s_status_group, TAG_PROCESSING_BIT);
            tag_handler(serial_no);
            xEventGroupWaitBits(s_status_group,
            TAG_DONE_BIT,
            pdTRUE,
            pdFALSE,
            TOUCH_TIMEOUT_MS/portTICK_PERIOD_MS);
            xEventGroupClearBits(s_status_group, TAG_PROCESSING_BIT);
            ESP_LOGI(TAG, "Tag done");

            if(xEventGroupGetBits(s_status_group) & TAG_PROCESSING_BIT)
            {
                ESP_LOGI(TAG,"Not disconnecting wifi - telemetry operation in progress");
            }
            else if(xEventGroupGetBits(s_status_group) & FIRMWARE_UPDATING_BIT)
            {
                ESP_LOGI(TAG,"Not disconnecting wifi - firmware update in progress");
            }
            else {
                ESP_LOGI(TAG, "Tag operation finished, disconnecting wifi");
                wifi_disconnect();
            }
        }

        // are all modem/unlocking/locking/LED tasks finished? can we sleep?
        // check if LED_IDLE && CAN_IDLE && WIFI_DISCONNECTED

        vTaskDelay(TAG_CHECK_INTERVAL_MS / portTICK_PERIOD_MS);

        // esp_sleep_enable_timer_wakeup(TAG_CHECK_INTERVAL_MS);
        // esp_light_sleep_start();
    }
    vTaskDelete(NULL);
}

void ibutton_init(void)
{
     // Create a 1-Wire bus, using the RMT timeslot driver
    owb = owb_rmt_initialize(&rmt_driver_info, ONEWIRE_PIN, RMT_CHANNEL_1, RMT_CHANNEL_0);
    owb_use_crc(owb, true);  // enable CRC check for ROM code
}

void app_main(void)
{
    hndl = calloc(1, sizeof(struct maxbox));
    hndl->vehicle = calloc(1, sizeof(struct vehicle));

    hndl->operator_car_lock = 0;

    io_init();
    led_init();
    flash_init();
    init_rfid();
    vehicle_init(hndl->vehicle);
    adc_calibration_init();
    wifi_init_sta();
    ibutton_init();
    led_update(IDLE);

    s_status_group = xEventGroupCreate();

    xTaskCreate(tag_loop, "tag_loop", 4096, NULL, 6, NULL);
    xTaskCreate(telemetry_loop, "telemetry_loop", 4096, NULL, 6, NULL);
    xTaskCreate(led_loop, "led_loop", 4096, NULL, 4, NULL);
    xTaskCreatePinnedToCore(can_receive_task, "can_receive_task", 4096, NULL, 3, NULL, tskNO_AFFINITY);
}

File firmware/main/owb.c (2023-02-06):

/*
 * MIT License
 *
 * Copyright (c) 2017 David Antliff
 * Copyright (c) 2017 Chris Morgan <chmorgan@gmail.com>
 *
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
 * THE SOFTWARE IS PROVIDED "AS IS", WITHOUT WARRANTY OF ANY KIND, EXPRESS OR
 * IMPLIED, INCLUDING BUT NOT LIMITED TO THE WARRANTIES OF MERCHANTABILITY,
 * FITNESS FOR A PARTICULAR PURPOSE AND NONINFRINGEMENT. IN NO EVENT SHALL THE
 * AUTHORS OR COPYRIGHT HOLDERS BE LIABLE FOR ANY CLAIM, DAMAGES OR OTHER
 * LIABILITY, WHETHER IN AN ACTION OF CONTRACT, TORT OR OTHERWISE, ARISING FROM,
 * OUT OF OR IN CONNECTION WITH THE SOFTWARE OR THE USE OR OTHER DEALINGS IN THE
 * SOFTWARE.
 */

/**
 * @file
 */

#include <stddef.h>
#include <stdbool.h>
#include <inttypes.h>
#include <string.h>
#include <stdlib.h>

#include "freertos/FreeRTOS.h"
#include "freertos/task.h"
#include "esp_log.h"
#include "sdkconfig.h"
#include "driver/gpio.h"

#include "owb.h"

static const char * TAG = "owb";

static bool _is_init(const OneWireBus * bus)
{
    bool ok = false;
    if (bus != NULL)
    {
        if (bus->driver)
        {
            // OK
            ok = true;
        }
        else
        {
            ESP_LOGE(TAG, "bus is not initialised");
        }
    }
    else
    {
        ESP_LOGE(TAG, "bus is NULL");
    }
    return ok;
}

/**
 * @brief 1-Wire 8-bit CRC lookup.
 * @param[in] crc Starting CRC value. Pass in prior CRC to accumulate.
 * @param[in] data Byte to feed into CRC.
 * @return Resultant CRC value.
 */
static uint8_t _calc_crc(uint8_t crc, uint8_t data)
{
    // https://www.maximintegrated.com/en/app-notes/index.mvp/id/27
    static const uint8_t table[256] = {
            0, 94, 188, 226, 97, 63, 221, 131, 194, 156, 126, 32, 163, 253, 31, 65,
            157, 195, 33, 127, 252, 162, 64, 30, 95, 1, 227, 189, 62, 96, 130, 220,
            35, 125, 159, 193, 66, 28, 254, 160, 225, 191, 93, 3, 128, 222, 60, 98,
            190, 224, 2, 92, 223, 129, 99, 61, 124, 34, 192, 158, 29, 67, 161, 255,
            70, 24, 250, 164, 39, 121, 155, 197, 132, 218, 56, 102, 229, 187, 89, 7,
            219, 133, 103, 57, 186, 228, 6, 88, 25, 71, 165, 251, 120, 38, 196, 154,
            101, 59, 217, 135, 4, 90, 184, 230, 167, 249, 27, 69, 198, 152, 122, 36,
            248, 166, 68, 26, 153, 199, 37, 123, 58, 100, 134, 216, 91, 5, 231, 185,
            140, 210, 48, 110, 237, 179, 81, 15, 78, 16, 242, 172, 47, 113, 147, 205,
            17, 79, 173, 243, 112, 46, 204, 146, 211, 141, 111, 49, 178, 236, 14, 80,
            175, 241, 19, 77, 206, 144, 114, 44, 109, 51, 209, 143, 12, 82, 176, 238,
            50, 108, 142, 208, 83, 13, 239, 177, 240, 174, 76, 18, 145, 207, 45, 115,
            202, 148, 118, 40, 171, 245, 23, 73, 8, 86, 180, 234, 105, 55, 213, 139,
            87, 9, 235, 181, 54, 104, 138, 212, 149, 203, 41, 119, 244, 170, 72, 22,
            233, 183, 85, 11, 136, 214, 52, 106, 43, 117, 151, 201, 74, 20, 246, 168,
            116, 42, 200, 150, 21, 75, 169, 247, 182, 232, 10, 84, 215, 137, 107, 53
    };

    return table[crc ^ data];
}

static uint8_t _calc_crc_block(uint8_t crc, const uint8_t * buffer, size_t len)
{
    do
    {
        crc = _calc_crc(crc, *buffer++);
        ESP_LOGD(TAG, "buffer 0x%02x, crc 0x%02x, len %d", (uint8_t)*(buffer - 1), (int)crc, (int)len);
    }
    while (--len > 0);
    return crc;
}

/**
 * @param[out] is_found true if a device was found, false if not
 * @return status
 */
static owb_status _search(const OneWireBus * bus, OneWireBus_SearchState * state, bool * is_found)
{
    // Based on https://www.maximintegrated.com/en/app-notes/index.mvp/id/187

    // initialize for search
    int id_bit_number = 1;
    int last_zero = 0;
    int rom_byte_number = 0;
    uint8_t id_bit = 0;
    uint8_t cmp_id_bit = 0;
    uint8_t rom_byte_mask = 1;
    uint8_t search_direction = 0;
    bool search_result = false;
    uint8_t crc8 = 0;
    owb_status status = OWB_STATUS_NOT_SET;

    // if the last call was not the last one
    if (!state->last_device_flag)
    {
        // 1-Wire reset
        bool is_present;
        bus->driver->reset(bus, &is_present);
        if (!is_present)
        {
            // reset the search
            state->last_discrepancy = 0;
            state->last_device_flag = false;
            state->last_family_discrepancy = 0;
            *is_found = false;
            return OWB_STATUS_OK;
        }

        // issue the search command
        bus->driver->write_bits(bus, OWB_ROM_SEARCH, 8);

        // loop to do the search
        do
        {
            id_bit = cmp_id_bit = 0;

            // read a bit and its complement
            bus->driver->read_bits(bus, &id_bit, 1);
            bus->driver->read_bits(bus, &cmp_id_bit, 1);

            // check for no devices on 1-wire (signal level is high in both bit reads)
            if (id_bit && cmp_id_bit)
            {
                break;
            }
            else
            {
                // all devices coupled have 0 or 1
                if (id_bit != cmp_id_bit)
                {
                    search_direction = (id_bit) ? 1 : 0;  // bit write value for search
                }
                else
                {
                    // if this discrepancy if before the Last Discrepancy
                    // on a previous next then pick the same as last time
                    if (id_bit_number < state->last_discrepancy)
                    {
                        search_direction = ((state->rom_code.bytes[rom_byte_number] & rom_byte_mask) > 0);
                    }
                    else
                    {
                        // if equal to last pick 1, if not then pick 0
                        search_direction = (id_bit_number == state->last_discrepancy);
                    }

                    // if 0 was picked then record its position in LastZero
                    if (search_direction == 0)
                    {
                        last_zero = id_bit_number;

                        // check for Last discrepancy in family
                        if (last_zero < 9)
                        {
                            state->last_family_discrepancy = last_zero;
                        }
                    }
                }

                // set or clear the bit in the ROM byte rom_byte_number
                // with mask rom_byte_mask
                if (search_direction == 1)
                {
                    state->rom_code.bytes[rom_byte_number] |= rom_byte_mask;
                }
                else
                {
                    state->rom_code.bytes[rom_byte_number] &= ~rom_byte_mask;
                }

                // serial number search direction write bit
                bus->driver->write_bits(bus, search_direction, 1);

                // increment the byte counter id_bit_number
                // and shift the mask rom_byte_mask
                id_bit_number++;
                rom_byte_mask <<= 1;
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
